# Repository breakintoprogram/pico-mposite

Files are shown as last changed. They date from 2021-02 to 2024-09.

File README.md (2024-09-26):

# pico-mposite

### Summary
Hardware and firmware for the Raspberry Pi Pico to add a composite video output using GPIO.

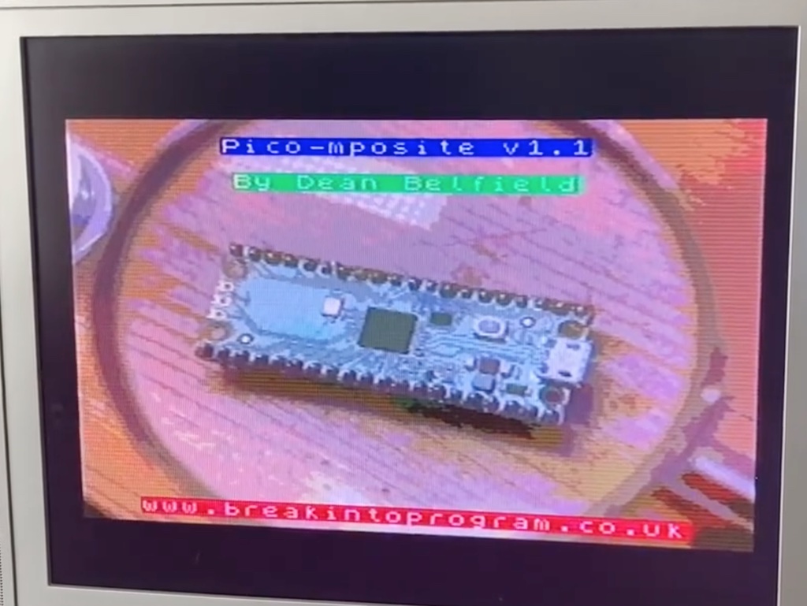
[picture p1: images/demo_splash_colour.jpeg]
Splash Screen


### Why am I doing this?
The code has evolved from a demo I built when the Pico was first released. I wanted a simple project that combined the use of DMA and the Pico PIO cores. Getting the Pico to output a composite video signal was a good candidate for that.

I decided the project had legs so updated the original mono version to add colour. This required a rewrite of my original demo and new hardware, yet both versions can still be built from this code. And both versions support a simple serial graphics terminal for homebrew 8-bit systems like my BSX and the RC2014. The capabilities of that may be expanded in future.

And I've also created PCB layouts for both versions. Files are available for the mono version, with the colour version to follow once I've tested it.

### Versions
There are two versions of the hardware and firmware

#### Mono
- 16 shades of grey

Uses a single resistor ladder to convert a 5-bit binary number on the Pico GPIO to a voltage between 0v and 1v. This is used to directly drive the composite video signal.

#### Colour
- 256 colours (322 RGB)

Uses three resistor ladders and an AD724 PAL/NTSC encoder chip.

Both monochrome and colour versions of the circut support resolutions of 256x192, 320x192 and 640x192.

For more details, see [my blog post detailing the build](http://www.breakintoprogram.co.uk/projects/pico/composite-video-on-the-raspberry-pi-pico).

### Hardware

#### Build on a breadboard
The breadboard files can be found in the folder [/hardware/breadboard/](/hardware/breadboard/)

#### Build on a PCB
The PCB gerber files, schematics and BOM can be found in the folder [/hardware/pcb/](/hardware/pcb/)

### Firmware
The code to use two PIO state machines. The first state machine creates a blank PAL(ish) video signal using a handful of 32-byte hard-coded lookup tables fetched via DMA, each pulse being 2us wide. At the point where pixel data needs to be injected into that signal a second state machine kicks in and writes that data out to the GPIO pins at a higher frequency, whilst the first state machine executes NOPs.

This allows for the horizontal video resolution to be tweaked independantly of the sync pulses, and is required for the colour version.

The firmware includes a handful of extras to get folk started on projects based upon this; some graphics primitives, and a handful of rolling demos.

The graphics primitives include:

- Plot and Line
- Circle, Triangle and Polygon (Wireframe and Filled)
- Print
- Clear Screen, Vsync and Border
- Scroll and Blit

There is also a terminal mode. This requires a serial connection to the UART on pins 12 and 13 of the Pico. Remember the Pico is not 5V tolerant; the sample circuits uses a resistor divider circuit to drop a 5V TTL serial connection to 3.3V. This is very much work-in-progress.

### Configuring for compilation
In config.h there are a couple of compilation options:
- opt_colour:
  - Set to 0 to build firmware for the mono version
  - Set to 1 to build firmware for the colour version
- opt_terminal
  - Set to 0 to just run rolling demos
  - Set to 1 to build the serial terminal

### Building
Make sure that you have set an environment variable to the Pico SDK, substituting the path with the location of the SDK files on your computer.
```shell
export PICO_SDK_PATH=/home/dev/pico/pico-sdk-2.0.0
```

To build, execute these commands inside the `build` folder.
```shell
cmake ..
make
```
This should create the file `pico-mposite.uf2` that you can upload to your Pico.

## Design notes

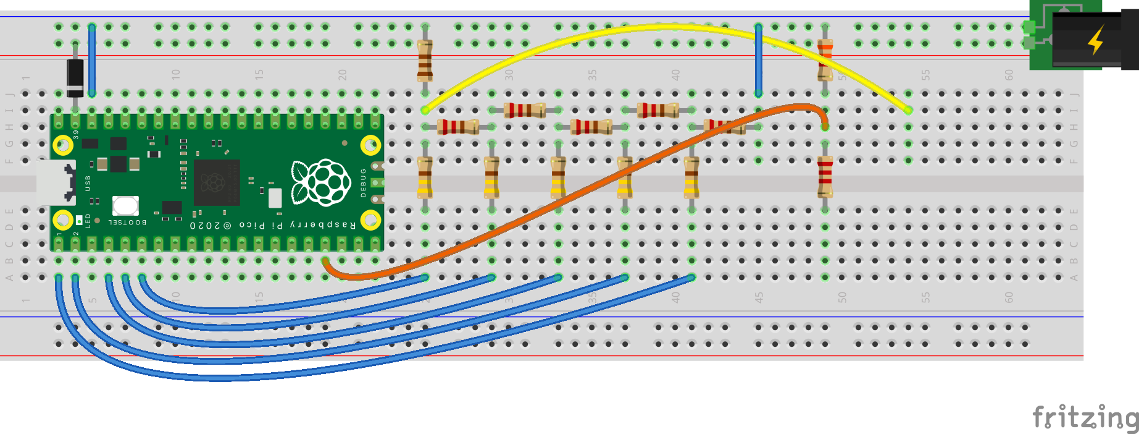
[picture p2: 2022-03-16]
hardware/breadboard/mono/Composite Video Mono Breadboard.png

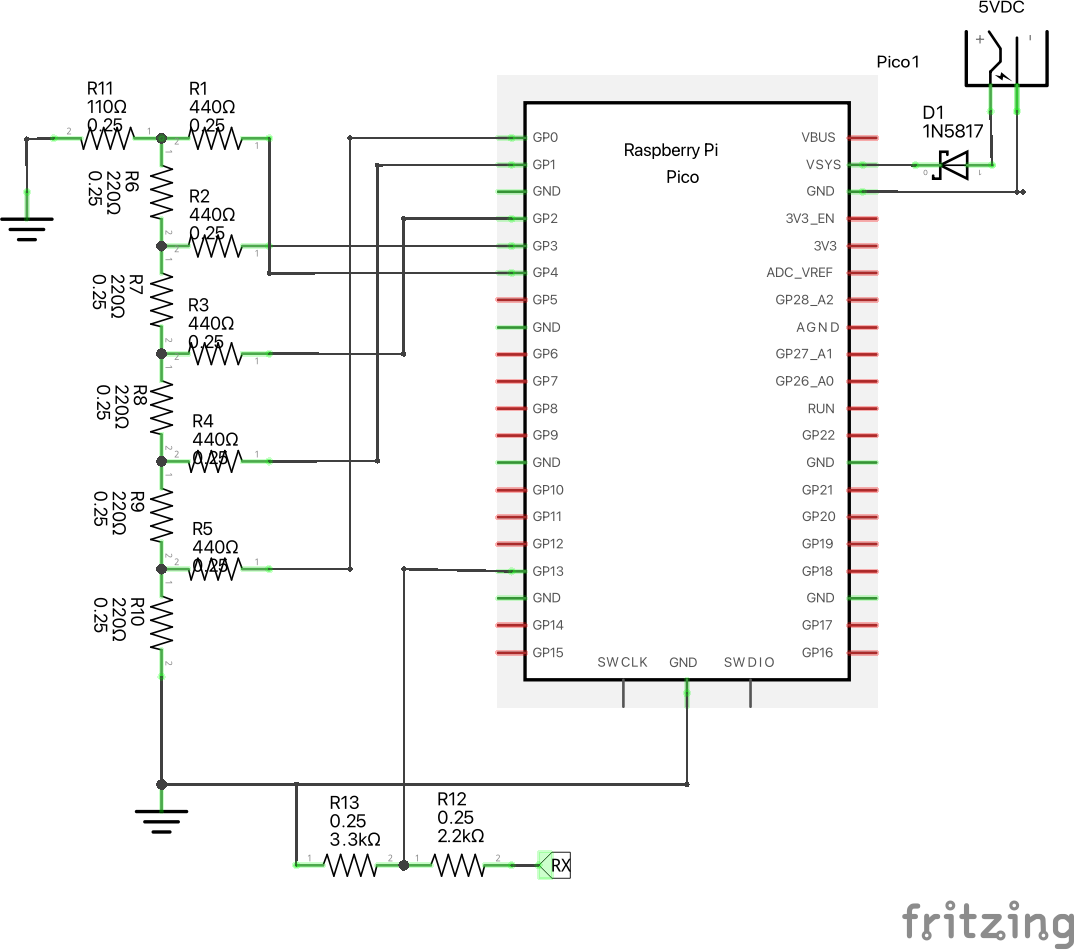
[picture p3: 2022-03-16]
hardware/breadboard/mono/Composite Video Mono Schematic.png

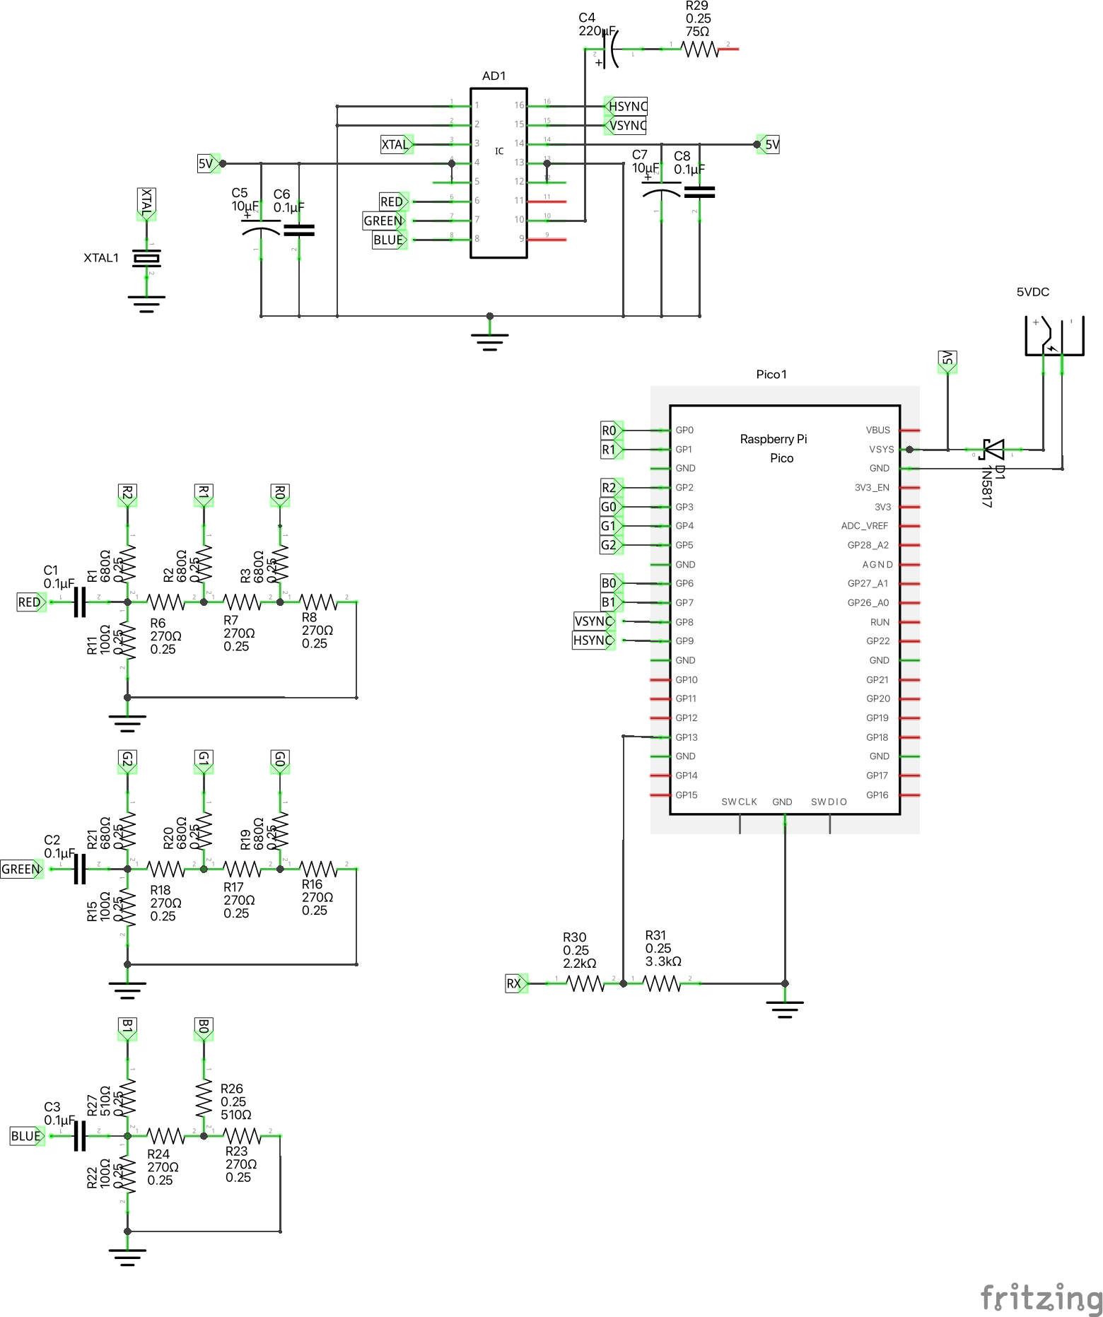
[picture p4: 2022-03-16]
hardware/breadboard/colour/Composite Video Colour Schematic.png

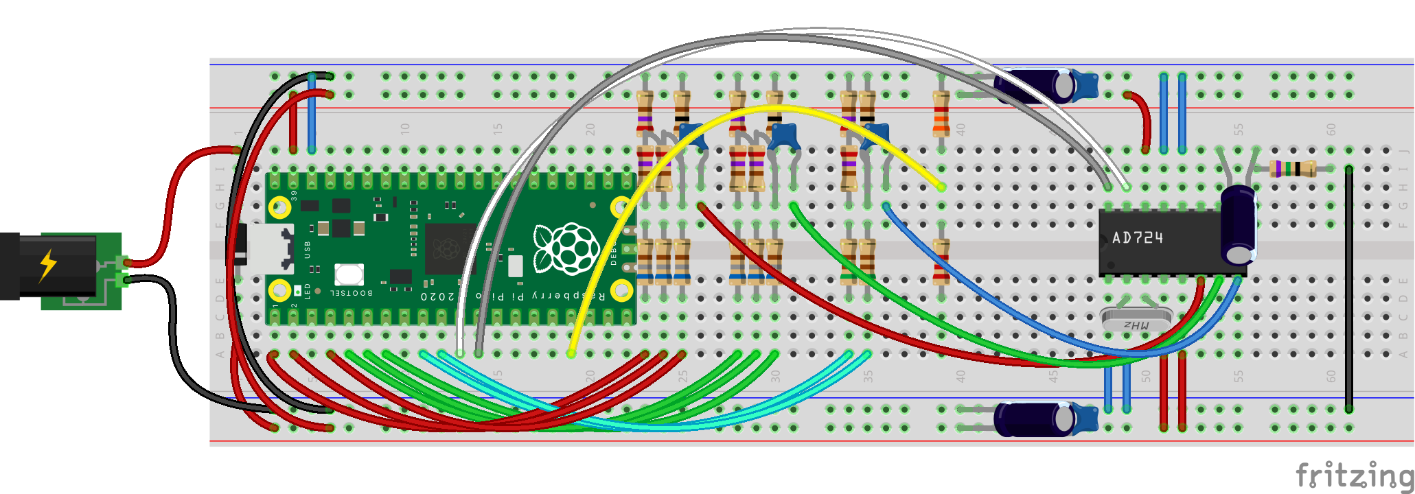
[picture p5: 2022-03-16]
hardware/breadboard/colour/Composite Video Colour Breadboard.png

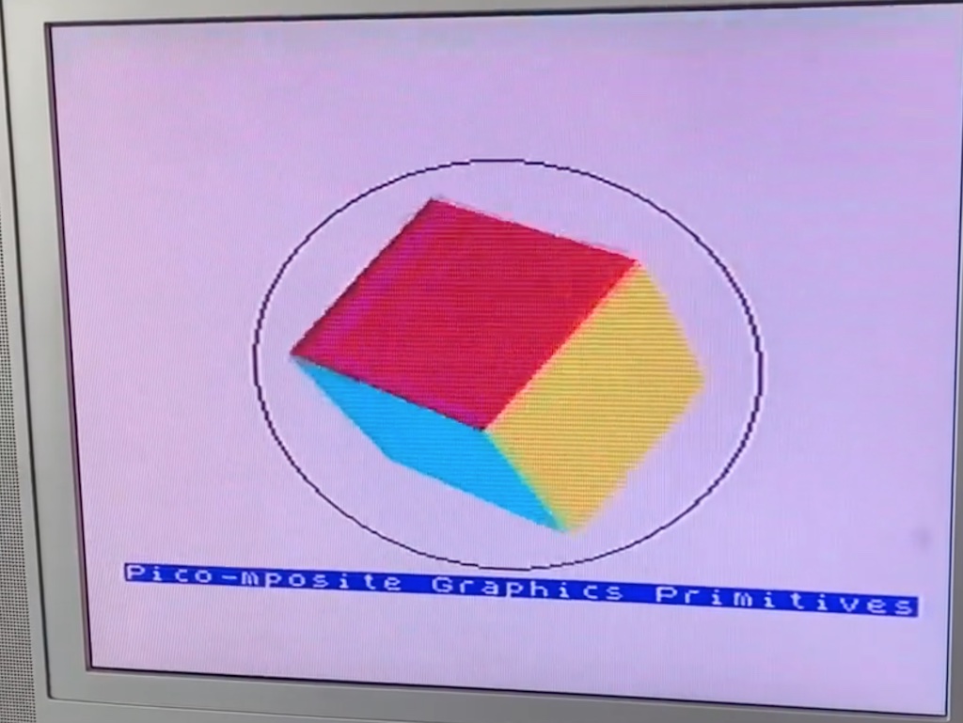
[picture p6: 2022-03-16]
images/demo_cube_colour.jpeg

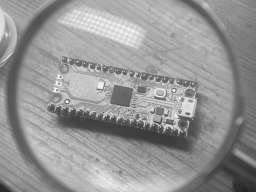
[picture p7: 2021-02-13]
images/bitmap.png

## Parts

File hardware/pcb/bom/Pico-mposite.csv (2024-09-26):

Reference | Value | Datasheet | Footprint | Qty | DNP
D1 | 1N5817 | http://www.vishay.com/docs/88525/1n5817.pdf | Diode_THT:D_DO-41_SOD81_P10.16mm_Horizontal | 1
J1 | PJRAN1X1U04X |  | Connector_Imported:SWITCHCRAFT_PJRAN1X1U04X | 1
J2,J3 | Conn_01x02_Socket | ~ | -- mixed values -- | 2
R1 | 110Ω | ~ | Resistor_THT:R_Axial_DIN0207_L6.3mm_D2.5mm_P10.16mm_Horizontal | 1
R2,R8,R9,R10,R11 | 440Ω | ~ | Resistor_THT:R_Axial_DIN0207_L6.3mm_D2.5mm_P10.16mm_Horizontal | 5
R3,R4,R5,R6,R7 | 220Ω | ~ | Resistor_THT:R_Axial_DIN0207_L6.3mm_D2.5mm_P10.16mm_Horizontal | 5
R12 | 3.3kΩ | ~ | Resistor_THT:R_Axial_DIN0207_L6.3mm_D2.5mm_P10.16mm_Horizontal | 1
R13 | 2.2kΩ | ~ | Resistor_THT:R_Axial_DIN0207_L6.3mm_D2.5mm_P10.16mm_Horizontal | 1
SW1 | SW_Push | ~ | Button_Switch_THT:SW_PUSH_6mm_H8mm | 1
U1 | Pico |  | MCU_RaspberryPi_and_Boards:RPi_Pico_SMD_TH | 1

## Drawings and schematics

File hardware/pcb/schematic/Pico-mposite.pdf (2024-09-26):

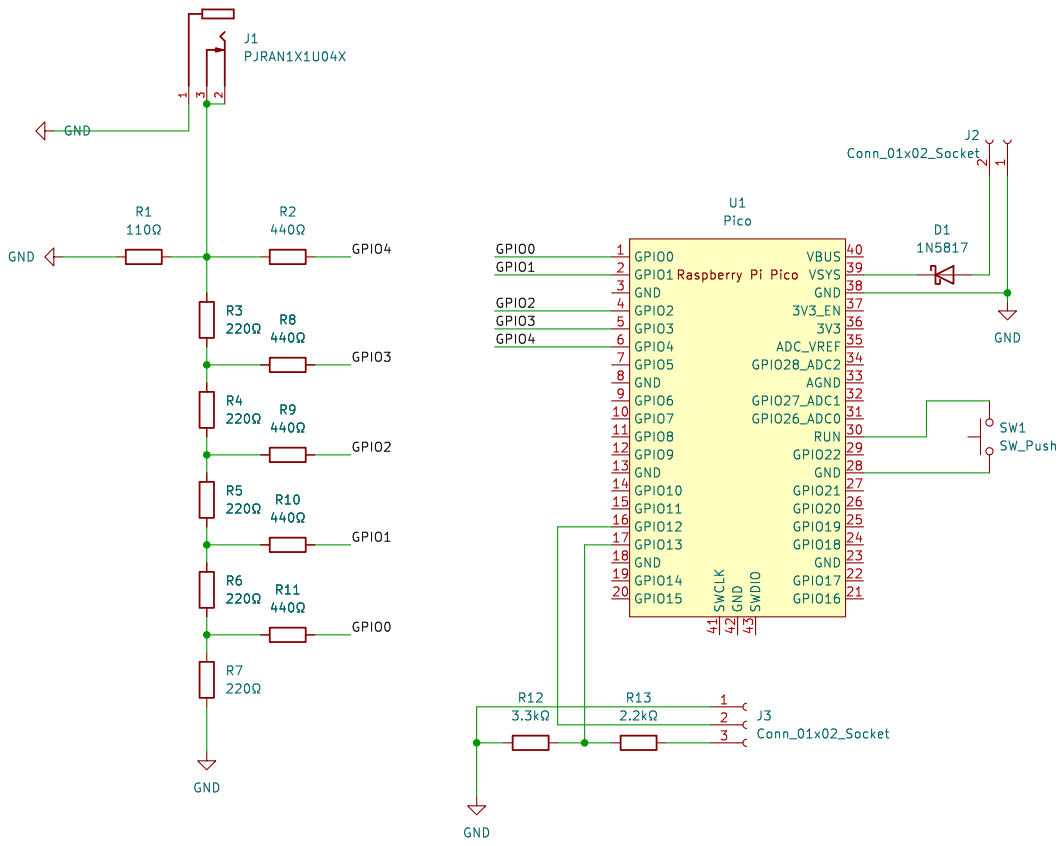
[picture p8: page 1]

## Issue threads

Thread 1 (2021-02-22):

External genlock

thomasvanta, 2021-02-22:
Amazing work.
How would you go to use this code with external sync, coming for example from a lm1881.
I guess one could configure interrupts per line and frame.

breakintoprogram, 2021-02-22:
Thank you.

I would probably start by attaching a sync signal to a GPIO pin and on a separate interrupt flush the FIFO, reset the variables vline and bline, and restart the PIO, to start video generation from scanline 1. Whether that could be done quick enough is a different question.

Hope that helps.

I will close this issue as it is outside of the scope of this project.

Closed 2021-02-22.

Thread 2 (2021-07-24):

How to build?

MrSurly, 2021-07-24:
The usual `cmake ..` from `build` doesn't work as expected.  I spent some time trying to fixup the cmake file without any luck.

```
build$ cmake ..
CMake Warning (dev) in CMakeLists.txt:
  No project() command is present.  The top-level CMakeLists.txt file must
  contain a literal, direct call to the project() command.  Add a line of
  code such as

    project(ProjectName)

  near the top of the file, but after cmake_minimum_required().

  CMake is pretending there is a "project(Project)" command on the first
  line.
This warning is for project developers.  Use -Wno-dev to suppress it.

-- The C compiler identification is GNU 10.3.0
-- The CXX compiler identification is GNU 10.3.0
-- Detecting C compiler ABI info
-- Detecting C compiler ABI info - done
-- Check for working C compiler: /usr/bin/cc - skipped
-- Detecting C compile features
-- Detecting C compile features - done
-- Detecting CXX compiler ABI info
-- Detecting CXX compiler ABI info - done
-- Check for working CXX compiler: /usr/bin/c++ - skipped
-- Detecting CXX compile features
-- Detecting CXX compile features - done
CMake Error at CMakeLists.txt:3 (pico_generate_pio_header):
  Unknown CMake command "pico_generate_pio_header".

CMake Warning (dev) in CMakeLists.txt:
  No cmake_minimum_required command is present.  A line of code such as

    cmake_minimum_required(VERSION 3.18)

  should be added at the top of the file.  The version specified may be lower
  if you wish to support older CMake versions for this project.  For more
  information run "cmake --help-policy CMP0000".
This warning is for project developers.  Use -Wno-dev to suppress it.

-- Configuring incomplete, errors occurred!
See also "/home/epoulsen/workspaces/pico-mposite/build/CMakeFiles/CMakeOutput.log".
```

breakintoprogram, 2021-08-01:
Hi, sorry for the delay in getting back to you. What platform are you building it on?

MrSurly, 2021-08-02:
Hey, no worries -- Ubuntu Linux

On Sun, Aug 1, 2021 at 8:22 AM Dean Belfield ***@***.***>
wrote:

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

breakintoprogram, 2022-02-01:
Ah, sorry for the delay in getting back to you - you will need to install the Raspberry Pi Pico C/C++ SDK from here:
https://www.raspberrypi.com/documentation/microcontrollers/c_sdk.html
There are some custom build steps to assemble the PIO code that require tools from that SDK.

orterforth, 2022-10-10:
Hi, this is a great project and really shows off PIO. I have the same issue and have tried both Ubuntu and MacOS Catalina. From what I see there is a dependency on pico-examples but I can't see what the correct relationship between them is; whether to clone as a child directory of pico-examples and add as a subdirectory to the pico-examples CMakeFiles.txt, or somehow pass PICO_EXAMPLES_PATH and get it to work that way. (I have tried all of these of course!) Would love to get the terminal mode working and try integrating it into other Pico projects.

breakintoprogram, 2024-09-26:
Hi @MrSurly @orterforth I've finally gotten around to fixing this - have merged in @kaspervn's changes this afternoon.

Closed 2024-09-26.

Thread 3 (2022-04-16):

Support BBC-Micro Style TTL C-Sync, R, G, B

sharpie7, 2022-04-16:
Thanks for an excellent project. I got a nice stable picture with the monochrome composite config at the first attempt.

Question: I am interested in making a simple pattern generator to test and debug Microvitec Cub monitors at the [National Museum of Computing](https://www.tnmoc.org/). That needs a signal that matches that from a BBC Micro, which is TTL level (1 bit) signals with Composite Sync, R, G, and B with PAL timing.

Looking at your work already it seems that should be fairly (!!) simple to add as a new colour option to the existing project. Is this something you would regard as potentially in-scope and be willing to collaborate on, or would you prefer if I worked on it solo?

One thing that isn't obvious to me from the code (and I haven't looked very hard) is the significance of all the bits in the 16 bit values you assign to identifiers like HSLO in cvideo.h. Can you explain what the bits do?

breakintoprogram, 2022-04-16:
Hi, no worries and thanks!

It should be fairly trivial to do a test signal generator for TTL monitors. The only complicated bit would be the TTL levels; the Pico GPIOs are 3.3V.

If I were to do that, I'd probably modify the colour version and:

- Discard the AD724 circuit and resistor ladders
- Use 3 GPIO pins for R, G and B (1 bit)
- Only have one SYNC GPIO pin rather than two
- Run those GPIO pins through a level converter to up them to TTL levels

You *may* get away with no level shifter as 3.3V GPIO is above the TTL trigger threshold.

The HSLO, HSHI, VSLO and VSHI values are for the low and high levels of the horizontal and vertical sync. These are specific bit values to set the GPIOs for the sync levels. For the monochrome version, this is a voltage of 0V (LO) and 0.4V (HI). For the colour version, it toggles two GPIO pins connected to the HSYNC and VSYNC pins on the AD724.

This is a little outside of the scope of this project, but am more than happy to help if you fork this project and need assistance.

sharpie7, 2022-04-17:
Thanks. That makes sense. I always forget that the Pi Pico is 3.3V, but it's not the end of the world to add a level shifter!

So, if I take the colour version as a starting point then:
```
    #define colour_base 0x00
    #define colour_max  0xFF
    #define HSLO        0x4200
    #define HSHI        0x4000
    #define VSLO        0x4100
    #define VSHI        0x4000
    #define BORD        0x8000
```

I assume that for HSLO and VSLO that bits 9 and 10 are the bits to go out to the SYNC GPIO pins, but why 0x4 at the start?

Similarly, why is BORD 0x8000 and not just 0?

breakintoprogram, 2022-04-17:
The 0x4nnn and 0x8nnn prefixes are ignored by the GPIO (as they are outside of the pins range of the PIO. The state machines use 0x0000 to exit a loop in cvidoe_sync.pio (line 20), and trigger cvideo_data.pio to start outputting pixel data (line 25).

As 0x0000 is a special word to say 'fill this block with pixel data', I needed to prevent HSHI and VSHI from being 0x0000, so use 0x4nnn to do that.

BORD is another special case; 0x8nnn marks out the border area. If you look at function set_border (cvideo.c, line 219), when setting the border lhs and rhs in the hsync table, I AND with BORD (0x8000). If that bit is set, I set the border colour, making sure I OR it with BORD (line 223).

sharpie7, 2022-04-24:
Thanks for the input. First release of my pattern generator based on the project is here:
[https://github.com/sharpie7/pico-pattern](https://github.com/sharpie7/pico-pattern)

breakintoprogram, 2022-04-26:
Nice one!

Closed 2024-09-26.

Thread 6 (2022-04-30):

16bit per pixel support

IanSB, 2022-04-30:
I've been working on this vintage computer HDMI upscaler project for the Pi Zero:
https://github.com/IanSB/RGBtoHDMI/wiki

This takes up to 12 bpp digital inputs + sync and I was looking at sharpie7's test pattern generator fork of your project and it seems like it should be possible to modify your design for 16bpp support as I want to generate at least 12bpp digital test patterns for testing RGBtoHDMI boards.

Would it be possible to change this for 16bpp support and separate H & V syncs or are there any underlying bandwidth limitations etc?

breakintoprogram, 2022-04-30:
The code has an option in config.h to compile a colour version; that splits the H and V syncs for the AD724 PAL encoder I use. With regards to upgrading it from 8bpp to 16bpp, the honest answer is I'm not 100% sure. It should just be a case of modding the colour version; increasing the number of pins allocated, modifying the resistor ladder, switching the pixel DMA from 8 to 16 bits, and doubling the malloc.

IanSB, 2022-06-06:
@breakintoprogram
@sharpie7

I spend a few hours yesterday modifying your code for 16bpp support after receiving the prototype PCBs for my RGBtoHDMI test jig and it all worked out extremely well:

Here's the test jig which has sockets for the various interfaces supported by RGBtoHDMI:

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

Here's the output displaying a test pattern (RGBtoHDMI can screencap the video source as a png):

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

The pixel data is on GPIOs 0-15 and the separate syncs are on GPIOs 16 & 17 although I'm mainly using 12 bits out of the 16bits of pixel data for 4 bits each of RGB.
I had to change the sync PIO to use 32 bit DMA and the video PIO to use 16 bit DMA and it all works well in 256 and 320 horizontal resolutions but appears to hang in 640 horizontal resolution so that may be too fast to do DMA on the pixel data at 16BPP and the sync nulls at 32bpp but 320 pixel is fine for my test jig at the moment.

One thing I noticed is that the default sync clock frequency seems to be producing slightly incorrect line timing with approx 64.5uS per line rather than 64uS.
#define piofreq_0 5.25f         // Clock frequency of state machine for PIO handling sync
Here is the RGBtoHDMI source summary screen showing the sync timings using your defaults:
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

I changed that to:
#define piofreq_0 5.2083f         // Clock frequency of state machine for PIO handling sync
which results in a 24Mhz PIO clock and 64uS lines.
Source summary screen again:
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

The other issue I had was that you are using separate clock frequencies for the sync and pixels and that results in the pixels jittering with respect to hsync. RGBtoHDMI does pixel perfect sampling by timing the sample points from the edge of hsync so any pixel jitter results in mis-sampling and resulting noise. I changed the 320 pixel mode clock divider also to 5.2083f which results in a pixel clock of 8Mhz and after that everything was jitter free. The pixel clock can be a different frequency but the relationship between the two clocks has to be carefully chosen to minimise or eliminate jitter.

Thanks for this very useful project.

IanSB, 2022-06-08:
@breakintoprogram

I'm having an issue with the relative phases of the hsync and pixel data which seems to start up randomly.
As mentioned RGBtoHDMI is very sensitive to phase offsets between hsync and the pixel data and I'm running both state machines at the same clock rate which keeps them frequency locked but the phase offset between the sync and pixels varies for each power up so I either get a clean or noisy image. It remains stable after the code has started but the phase offset on the next power up will be different.
I presume this is because the two state machines don't start up at the same time. I have changed the code so that the state machines are both started immediately one after the other but it still varies randomly.
Is there any way to start them reliably in sync? (I suspect the startup code varies in execution time due to cache misses and random cache allocation and I guess it only needs a few clock cycles difference in execution time for that to be an issue)

sharpie7, 2022-06-08:
@IanSB

Thanks for tagging me on this. I had seen the horizontal jitter in the output but hadn't been able to find the cause or even measure it properly, so I convinced myself it was a problem of my imagination or my display. I will try your clock fix.

For the synchronization of state machines this discussion seems relevent. It seems you can hold state machines in reset and start them together in blocks:
https://github.com/raspberrypi/pico-feedback/issues/65

IanSB, 2022-06-08:
@sharpie7
>For the synchronization of state machines this discussion seems relevent.

Yes, the problem is that it's the state machines' clock dividers that are out of sync rather than the state machines themselves and is the same type of issue that another user had recently on stardot with a BBC mode7 clock divider:
https://stardot.org.uk/forums/viewtopic.php?p=358299#p358299

I first used pio_clkdiv_restart_sm_mask then started the state machines:

    pio_clkdiv_restart_sm_mask(pio_0, (1u << sm_data) | (1u << sm_sync));
    pio_sm_set_enabled(pio_0, sm_data, true);	// Enable the PIO state machine
    pio_sm_set_enabled(pio_0, sm_sync, true);	// Enable the PIO state machine

But then I noriced that this calll does all of the above simultaneously:

    pio_enable_sm_mask_in_sync(pio_0, (1u << sm_data) | (1u << sm_sync));

After making the above change it always starts up with the pixels and sync in the same phase and I now have a stable phase locked test source.

>I will try your clock fix

As mentioned above, the clocks don't have to be the same but to avoid jitter the pixel clock must have a whole number of cycles in the exact time taken for the sync pio to produce one line. This time is nominally 512 cycles of 8 Mhz, however I'm not sure the clock divider is producing exactly 24 Mhz (8*3) nominal for the pio because the fractional divider has limited bits so you would need to work out the exact nominal frequencies that both pio dividers were producing to be able to check for jitter free operation.

IanSB, 2023-02-08:
@sharpie7
@runnerpack
>Maybe there's a compression algorithm fast enough to squeeze it in there.

I did get it effectively working at 640x256x16bpp to allow some 80 column text with my test pattern by sending the first 16 lines out and then repeating each line after that twice so that the video memory buffer was only 640x136 (16 lines at full vertical resolution and 120 lines at half vertical resolution for a total of 174080 bytes)

This worked well for my test pattern:
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

As the start of each video line is under software control you could dynamically vary the vertical resolution to match the displayed image e.g. with the above pattern I only really needed 16 lines for the text and 6 lines for the rest repeated many times but I left it at half resolution so there was some flexibility for more complex test patterns in future.

runnerpack, 2023-02-08:
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

That's a really clever solution! 👍🏻

breakintoprogram, 2024-09-26:
Hi @IanSB I've finally gotten around to updating this project - will take a look at some of your suggestions regarding the jitters.

breakintoprogram, 2024-09-27:
I've implemented the simultaneous PIO state machine start thanks. Will review the horizontal dot frequency as reducing the value I put in leads to a loss of sync. I suspect that's more down to running it on a breadboard. Will review that when the PCB comes in.

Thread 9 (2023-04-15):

Supporto for 60hz refresh

DnaX, 2023-04-15:
What can I modify to change the hscan to generate a proper 60Hz signal instead 50Hz?

Pancra85, 2025-06-03:
I think you could at first glance modify the CPU Speed of the Pico maybe

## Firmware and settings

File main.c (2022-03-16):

//
// Title:	        Pico-mposite Video Output
// Description:		A hacked-together composite video output for the Raspberry Pi Pico
// Author:	        Dean Belfield
// Created:	        02/02/2021
// Last Updated:	01/03/2022
// 
// Modinfo:
// 04/02/2022:      Demos now set the border colour
// 05/02/2022:      Added support for colour
// 20/02/2022:      Added demo_terminal
// 01/03/2022:      Added colour to the demos

#include <stdlib.h>
#include <math.h>

#include "memory.h"
#include "pico/stdlib.h"

#include "hardware/pio.h"
#include "hardware/dma.h"
#include "hardware/irq.h"   

#include "bitmap.h"
#include "graphics.h"
#include "cvideo.h"
#include "terminal.h"

#include "main.h"

// Cube corner points
//
int shape_pts[8][8] = {
    { -20,  20,  20 },
    {  20,  20,  20 },
    { -20, -20,  20 },
    {  20, -20,  20 },
    { -20,  20, -20 },
    {  20,  20, -20 },
    { -20, -20, -20 },
    {  20, -20, -20 },
};

// Cube polygons (lines between corners + colour)
//
#if opt_colour == 0

int shape[6][5] = {
    { 0,1,3,2, 1 },
    { 6,7,5,4, 2 },
    { 1,5,7,3, 3 },
    { 2,6,4,0, 4 },
    { 2,3,7,6, 5 },
    { 0,4,5,1, 6 },
};

unsigned char col_mandelbrot[16] = {
    0, 1, 2, 3, 4, 5, 6, 7, 8, 9, 10, 11, 12, 13, 14, 15
};

#else

int shape[6][5] = {
    { 0,1,3,2, col_red },
    { 6,7,5,4, col_green },
    { 1,5,7,3, col_blue },
    { 2,6,4,0, col_magenta },
    { 2,3,7,6, col_cyan },
    { 0,4,5,1, col_yellow },
};

unsigned char col_mandelbrot[16] = { 
    rgb(0,0,0),
    rgb(1,0,0),
    rgb(2,0,0),
    rgb(3,0,0),
    rgb(4,0,0),
    rgb(5,0,0),
    rgb(6,0,0),
    rgb(7,0,0),
    rgb(7,0,0),
    rgb(7,1,0),
    rgb(7,2,0),
    rgb(7,3,0),
    rgb(7,4,0),
    rgb(7,5,0),
    rgb(7,6,0),
    rgb(7,7,0)
};

#endif

// The main loop
//
int main() {
    initialise_cvideo();    // Initialise the composite video stuff
    //
    // And then just loop doing your thing
    //
    while(true) {
        demo_splash();
        #if opt_terminal == 1
        demo_terminal();
        #else 
        demo_spinny_cube();
        demo_mandlebrot(); 
        #endif
    }
}

void demo_splash() {
    cls(0);
    blit(&sample_bitmap, 0, 0, 256, 192, (width - 256) / 2, 0);
    #if opt_colour == 0
    set_border(col_black);
    print_string(60, 8, "Pico-mposite v"version, col_black, col_white);
    print_string(64, 24, "By Dean Belfield", col_black, col_white);
    print_string(24, 180, "www.breakintoprogram.co.uk", col_black, col_white);
    #else
    set_border(col_blue);
    print_string(60, 8, "Pico-mposite v"version, col_blue, col_white);
    print_string(64, 24, "By Dean Belfield", col_green, col_white);
    print_string(24, 180, "www.breakintoprogram.co.uk", col_red, col_white);    
    #endif 
    sleep_ms(10000);
}

// Demo: Spinning 3D cube
//
void demo_spinny_cube() {
    double the = 0;
    double psi = 0;
    double phi = 0;

    set_border(col_white);

    for(int i = 0; i < 1000; i++) {
        wait_vblank();
        cls(col_white);
        #if opt_colour == 0
        print_string(0, 180, "Pico-mposite Graphics Primitives", 15, 0);
        #else
        print_string(0, 180, "Pico-mposite Graphics Primitives", col_blue, col_white);
        #endif 
        draw_circle(128, 96, 80, i >= 500 ? col_grey : col_black, i >= 500);
        render_spinny_cube(0, 0, the, psi, phi, i >= 500);
        the += 0.01;
        psi += 0.03;
        phi -= 0.02;
    }
}

// Demo: Mandlebrot set
//
void demo_mandlebrot() {
    cls(col_black);
    set_border(col_black);
    render_mandlebrot();
    #if opt_colour == 0
    print_string(16, 180, "Pico-mposite Mandlebrot Demo", 0, 15);
    #else
    print_string(16, 180, "Pico-mposite Mandlebrot Demo", col_red, col_white);
    #endif
    sleep_ms(10000);
}

// Draw a 3D cube
// xo: X position in view
// yo: Y position in view
// the, psi, phi: Rotation angles
// colour: Pixel colour
//
void render_spinny_cube(int xo, int yo, double the, double psi, double phi, bool filled) {
    int i;
    double x, y, z, xx, yy, zz;
    int a[8], b[8];
    int xd =0, yd = 0;
    int x1, y1, x2, y2, x3, y3, x4, y4;
    double sd = 512, od = 256;

    for(i = 0; i < 8 ; i++) {
        xx = shape_pts[i][0];
        yy = shape_pts[i][1];
        zz = shape_pts[i][2];

         y = yy * cos(phi) - zz * sin(phi);
        zz = yy * sin(phi) + zz * cos(phi);
         x = xx * cos(the) - zz * sin(the);
        zz = xx * sin(the) + zz * cos(the);
        xx =  x * cos(psi) -  y * sin(psi);
        yy =  x * sin(psi) +  y * cos(psi);

        xx += xo + xd;
        yy += yo + yd;

        a[i] = 128 + xx * sd / (od - zz);
        b[i] =  96 + yy * sd / (od - zz);
    }

    for(i = 0; i < 6; i++) {
        x1 = a[shape[i][0]];
        x2 = a[shape[i][1]];
        x3 = a[shape[i][2]];
        x4 = a[shape[i][3]];
        y1 = b[shape[i][0]];
        y2 = b[shape[i][1]];
        y3 = b[shape[i][2]];
        y4 = b[shape[i][3]];

        if(x1 * (y2 - y3) + x2 * (y3 - y1) + x3 * (y1 - y2) <= 0) {
            draw_polygon(x1, y1, x2, y2, x3, y3, x4, y4, shape[i][4], filled);
        }
    }
}

// Draw a Mandlebrot
//
void render_mandlebrot(void) {
    int k = 0;
    float i , j , r , x , y;
    for(y = 0; y < height; y++) {
        for(x = 0; x < width; x++) {
            plot(x, y, col_mandelbrot[k]);
            for(i = k = r = 0; j = r * r - i * i - 2 + x / 100, i = 2 * r * i + (y - 96) / 70, j * j + i * i < 11 && k++ < 15; r = j);
        }
    }
}

// Simple terminal output from UART
//
void demo_terminal(void) {
    initialise_terminal();  // Initialise the UART
    set_mode(2);
    set_border(col_terminal_border);
    cls(col_terminal_bg);
    terminal();             // And do the terminal
    set_mode(0);
}

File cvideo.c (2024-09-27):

//
// Title:	        Pico-mposite Video Output
// Description:		The composite video stuff
// Author:	        Dean Belfield
// Created:	        26/01/2021
// Last Updated:	27/09/2024
//
// Modinfo:
// 15/02/2021:      Border buffers now have horizontal sync pulse set correctly
//                  Decreased RAM usage by updating the image buffer scanline on the fly during the horizontal interrupt
//					Fixed logic error in cvideo_dma_handler; initial memcpy done twice
// 31/01/2022:      Refactored to use less memory
//					Split the video generation into two state machines; sync and data
// 01/02/2022:      Added a handful of graphics primitives
// 02/02/2022:      Split main loop out into main.c
// 04/02/2022:      Added set_border
// 05/02/2022:      Added support for colour, fixed bug in video generation
// 20/02/2022:      Bitmap is now dynamically allocated; added two higher resolution video modes
// 25/02/2022:      Lengthened HSYNC to 12us
// 27/09/2024:		PIO state machines now started simultaneously

#include <stdlib.h>

#include "memory.h"
#include "pico/stdlib.h"

#include "hardware/pio.h"
#include "hardware/dma.h"
#include "hardware/irq.h"   

#include "charset.h"            // The character set
#include "cvideo.h"
#include "graphics.h"
#include "cvideo_sync.pio.h"    // The assembled PIO code
#include "cvideo_data.pio.h"

PIO pio_0;                      // The PIO that this uses
uint offset_0;                  // Program offsets
uint offset_1;

uint dma_channel_0;             // DMA channel for transferring sync data to PIO
uint dma_channel_1;             // DMA channel for transferring pixel data data to PIO
uint vline;                     // Current PAL(ish) video line being processed
uint bline;                     // Line in the bitmap to fetch

uint vblank_count;              // Vblank counter

unsigned char * bitmap;         // Bitmap buffer

int width = 256;                // Bitmap dimensions             
int height = 192;

/*
 * The sync tables consist of 32 entries, each one corresponding to a 2us slice of the 64us
 * horizontal sync. The value 0x00 is reserved as a control byte for the horizontal sync;
 * cvideo_sync will not write to the GPIO for that block of 0x00's.
 * 
 * All sync pulses are active low
 */

// Horizontal sync with gap for pixel data
//
unsigned short hsync[32] = {
    HSLO, HSLO, HSHI, HSHI, HSHI, HSHI, BORD, BORD, 0x00, 0x00, 0x00, 0x00, 0x00, 0x00, 0x00, 0x00,
    0x00, 0x00, 0x00, 0x00, 0x00, 0x00, 0x00, 0x00, 0x00, 0x00, 0x00, 0x00, 0x00, BORD, BORD, BORD,
};

// Horizontal sync for top and bottom borders
//
unsigned short border[32] = {
    HSLO, HSLO, HSHI, HSHI, HSHI, HSHI, BORD, BORD, BORD, BORD, BORD, BORD, BORD, BORD, BORD, BORD, 
    BORD, BORD, BORD, BORD, BORD, BORD, BORD, BORD, BORD, BORD, BORD, BORD, BORD, BORD, BORD, BORD, 
};

// Vertical sync (long/long)
//
unsigned short vsync_ll[32] = {
    VSLO, VSLO, VSLO, VSLO, VSLO, VSLO, VSLO, VSLO, VSLO, VSLO, VSLO, VSLO, VSLO, VSLO, VSLO, VSHI, // Long sync pulse
    VSLO, VSLO, VSLO, VSLO, VSLO, VSLO, VSLO, VSLO, VSLO, VSLO, VSLO, VSLO, VSLO, VSLO, VSLO, VSHI, // Long sync pulse
};

// Vertical sync (short/short)
//
unsigned short vsync_ss[32] = {
    VSLO, VSHI, VSHI, VSHI, VSHI, VSHI, VSHI, VSHI, VSHI, VSHI, VSHI, VSHI, VSHI, VSHI, VSHI, VSHI, // Short sync pulse
    VSLO, VSHI, VSHI, VSHI, VSHI, VSHI, VSHI, VSHI, VSHI, VSHI, VSHI, VSHI, VSHI, VSHI, VSHI, VSHI, // Short sync pulse
};

// Vertical sync (long/short)
//
unsigned short vsync_ls[32] = {
    VSLO, VSLO, VSLO, VSLO, VSLO, VSLO, VSLO, VSLO, VSLO, VSLO, VSLO, VSLO, VSLO, VSLO, VSLO, VSHI, // Long sync pulse
    VSLO, VSHI, VSHI, VSHI, VSHI, VSHI, VSHI, VSHI, VSHI, VSHI, VSHI, VSHI, VSHI, VSHI, VSHI, VSHI, // Short sync pulse
};

/*
 * The main routine sets up the whole shebang
 */
int initialise_cvideo(void) { 
    pio_0 = pio0;	                    // Assign the PIO

    // Load up the PIO programs
    //
    offset_0 = pio_add_program(pio_0, &cvideo_sync_program);
    offset_1 = pio_add_program(pio_0, &cvideo_data_program);

    dma_channel_0 = dma_claim_unused_channel(true);	// Claim a DMA channel for the sync
    dma_channel_1 = dma_claim_unused_channel(true);	// And one for the pixel data

    vline = 1;          // Initialise the video scan line counter to 1
    bline = 0;	        // And the index into the bitmap pixel buffer to 0
    vblank_count = 0;   // And the vblank counter

	// Initialise the first PIO (video sync)
	//
    pio_sm_set_enabled(pio_0, sm_sync, false);	// Disable the PIO state machine
    pio_sm_clear_fifos(pio_0, sm_sync);			// Clear the PIO FIFO buffers
    cvideo_sync_initialise_pio(					// Initialise the PIO (function in cvideo.pio)
		pio_0,									// The PIO to attach this state machine to
		sm_sync,								// The state machine number
		offset_0,								// And offset
		gpio_base,								// Start pin in the GPIO
		gpio_count,								// Number of pins
		piofreq_0								// State machine clock frequency
	);	
    cvideo_configure_pio_dma(					// Configure the DMA
        pio_0,									// The PIO to attach this DMA to
        sm_sync,								// The state machine number
        dma_channel_0,							// The DMA channel
        DMA_SIZE_16,                            // Size of each transfer
        32,										// Number of bytes to transfer
        cvideo_dma_handler						// The DMA handler
    );

    bitmap = malloc(width * height);            // Allocate the bitmap memory

	// Initialise the second PIO (pixel data)
	//
    cvideo_data_initialise_pio(					
		pio_0,
		sm_data,
		offset_1,
		gpio_base,
		gpio_count,
		piofreq_1_256
	);

    // Initialise the DMA
    //
    cvideo_configure_pio_dma(
        pio_0,	
        sm_data,
        dma_channel_1,							// On DMA channel 1
        DMA_SIZE_8,                             // Size of each transfer
        width,									// The bitmap width
        NULL									// But there is no DMA interrupt for the pixel data
    ); 

    irq_set_exclusive_handler(					// Set up the PIO IRQ handler
		PIO0_IRQ_0,								// The IRQ #
		cvideo_pio_handler						// And handler routine
	); 
    pio0_hw->inte0 = PIO_IRQ0_INTE_SM0_BITS;	// Just for IRQ 0 (triggered by irq set 0 in PIO)
    irq_set_enabled(PIO0_IRQ_0, true);			// Enable it    

    set_border(0);                              // Set the border colour
    cls(0);                                     // Clear the screen      

	// Start the PIO state machines
	//
	pio_enable_sm_mask_in_sync(pio_0, (1u << sm_data) | (1u << sm_sync));
    return 0;
}
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

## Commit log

2021-02-15 Fixed logic error in cvideo_dma_handler
    [cvideo.c]
2022-02-04 Fixed bug in print_char, typos in comments
2022-02-04 Border colour can now be set from the ARM core
2022-02-07 Added support for colour, bug fixes
    [cvideo.c]
2022-04-21 cvideo_data.pio for non-zero pin_base
    Currently if the pin-base is not zero the wrong data is read into Y at the start of the loop meaning the border if not restored at the end. This corrects that problem.
2023-08-22 Fix some global variables being defined in every header by declaring them external.
    [cvideo.h]
2024-09-26 Removed sample build files
2024-09-26 Moved to new folder
    [Composite Video Colour #1.0.fzz, Composite Video Mono #1.0.fzz, Composite Video Mono #1.1.fzz]
2024-09-26 Added link for mono pcb files
